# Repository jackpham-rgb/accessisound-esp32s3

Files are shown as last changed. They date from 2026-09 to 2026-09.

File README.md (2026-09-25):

# AccessiSound

An assistive device built around an ESP32-S3 that listens to the room,
recognizes sounds, and tells the user about them. It has three real
versions, described below. This repo holds the sound-recognition code, the
hardware documentation and a 3D model of the v2 enclosure.

| Version | What it was | Hardware |
|---|---|---|
| **v1** | Hackathon prototype, SoDA Hacks, March 7, 2026 | ESP32-S3-BOX-3 dev kit (borrowed) |
| **v2** | Rebuilt at home with my own parts and a custom enclosure | ESP32-S3 dev board, ESP32-CAM, 1.54 inch display |
| **v2.5** | Gift version built for a friend | v2 plus kitchen object recognition and a mochi animation |

## v1: the hackathon prototype

Built at SoDA Hacks, UC Berkeley, on Saturday, March 7, 2026. It ran on an
ESP32-S3-BOX-3, an off-the-shelf Espressif dev kit
([espressif/esp-box](https://github.com/espressif/esp-box)) that CSUA (the
Computer Science Undergraduate Association at my school) lent out for the
hackathon. I did not design or build an enclosure for v1. Its physical form
is the BOX-3 as sold, not something I made.

> It was my first hackathon, and I learned a lot from both the experience and the people I met there. I built an assistive device using an ESP32-S3 that could recognize speech and surrounding sounds, then provide real-time descriptions to support accessibility. I also trained the system using basic inputs, online datasets, and CSUA HPC resources.

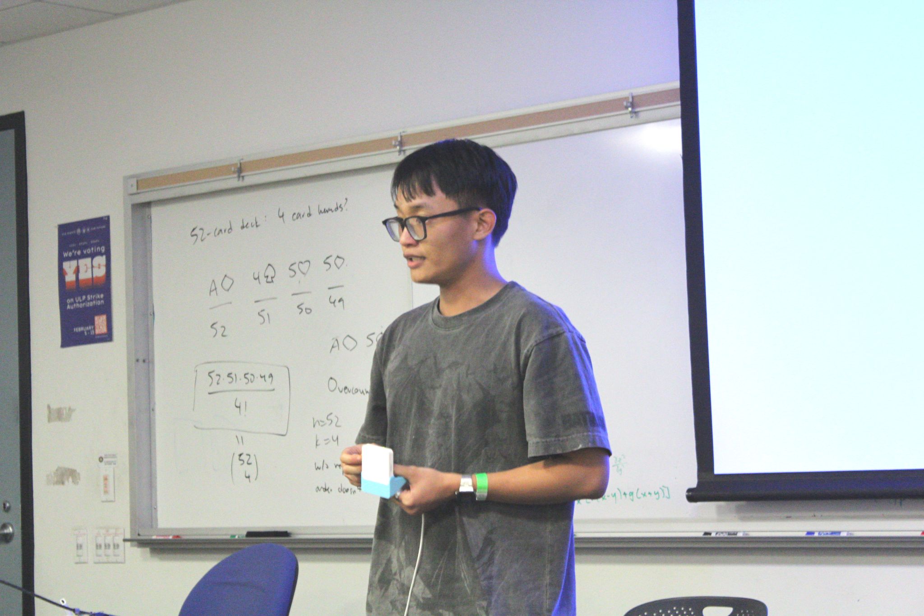
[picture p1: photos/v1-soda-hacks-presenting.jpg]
Presenting v1 at SoDA Hacks


*Presenting v1 at SoDA Hacks, holding the ESP32-S3-BOX-3.*

## v2: rebuilt at home

After the hackathon I bought my own ESP32 board and components and rebuilt
it as a custom device. Most parts came from AliExpress, but that seller is
gone. The display is a 1.54 inch full color TFT, 240 x 240 pixels, ST7789
driver, SPI interface, 3.3 V, 65K colors. An equivalent part is on Amazon:
[B0GVYMJVWH](https://www.amazon.com/dp/B0GVYMJVWH). Everything else was
generic online parts.

Components:

- ESP32-S3 dev board (the repo firmware targets the ESP32-S3-DevKitC-1)
- ESP32-CAM module
- 1.54 inch ST7789 SPI display (above)
- INMP441 I2S microphone
- USB-C charging circuit (TP4056 class module) and a small LiPo battery
- Vibration motor, buzzer and two status LEDs, as in the original parts list

I imitated the look of the ESP32-S3-BOX-3, but the finished enclosure ended
up looking like a vintage Macintosh 128K.

Even though there is no photo of the physical v2 unit, the picture below
accurately represents the model made using Autodesk Fusion.

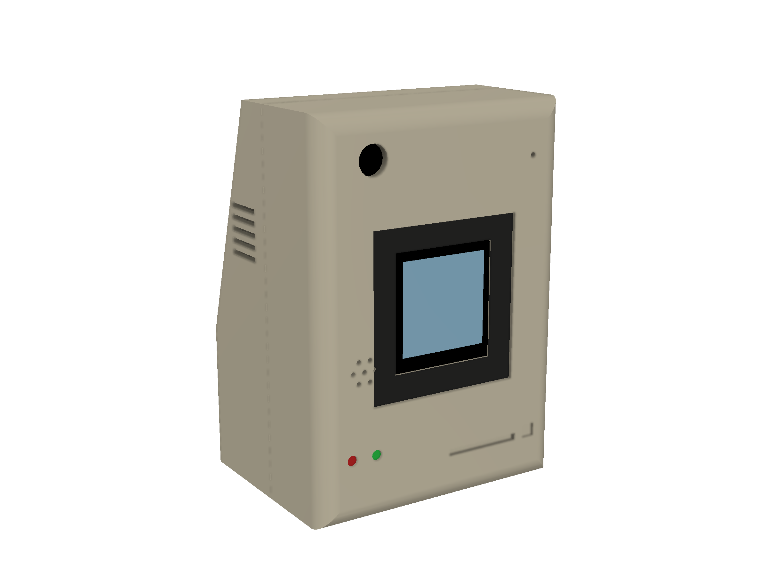
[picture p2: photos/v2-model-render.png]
v2 model, exterior


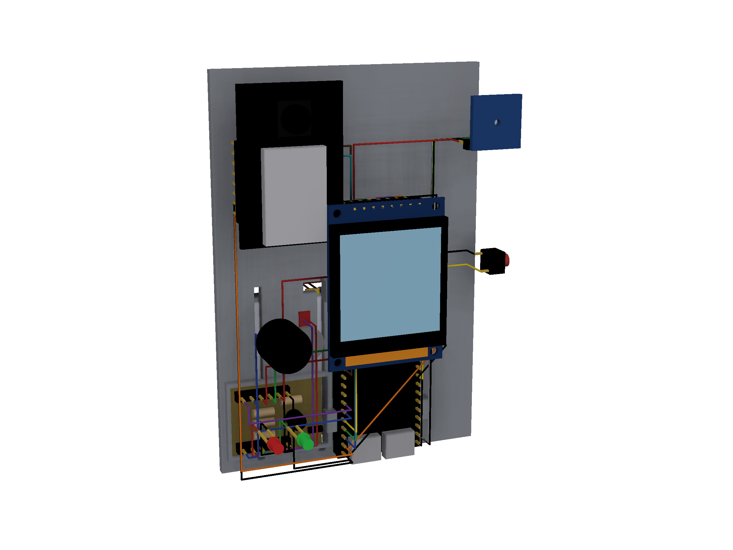
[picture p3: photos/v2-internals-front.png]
v2 model, internal layout and wiring


Model files, parts list with dimensions, wiring tables and print notes are
in [hardware/v2](hardware/v2/README.md):

- [Fusion 360 archive (.f3d)](hardware/v2/accessisound_v2_assembly.f3d) and [STEP](hardware/v2/accessisound_v2_assembly.step)
- STL files for the [front shell](hardware/v2/stl/enclosure_front.stl), [back shell](hardware/v2/stl/enclosure_back.stl), [mounting plate](hardware/v2/stl/mount_plate.stl), and one [build-plate layout](hardware/v2/stl/print_plate_layout.stl)

## v2.5: the gift version

I built this while moving out of the dorm for summer break. I adapted the
v1 to v2 design for a friend's needs: his family has hearing and visual
impairments. I added kitchen object recognition through the ESP32-CAM and a
cute mochi character animation on the display to make it feel friendlier.
I gave it to him as a thank you for helping me brainstorm the original
hackathon idea. He still uses it every day in his dorm kitchen.

This device used to be listed separately on my resume and site as "AI
Kitchen Accessibility Assistant". It is the same device, not a separate
project.

The camera and animation code is not in this repo yet. What is here is the
sound-recognition pipeline described next.

## How the sound recognition works

The device listens through a microphone, turns each 32 ms slice of audio
into 13 numbers (MFCCs), stacks 32 slices into a 0.53 second window, and
runs a small CNN over it. If the top guess is at least 72 percent
confident, it fires an alert. Everything runs entirely on the ESP32-S3.

`ml/visualize_pipeline.py` draws every step using the firmware's own math,
rewritten in NumPy. It doesn't need a large dataset or any dedicated
hardware, just numpy, scipy and matplotlib:

```bash
cd ml
pip install numpy scipy matplotlib
python visualize_pipeline.py            # built-in synthetic chime, or pass a WAV
python check_against_firmware.py        # optional: compiles the real firmware code with g++ and compares
```

The check compiles `firmware/src/feature_extractor.h` and compares it to the
NumPy version on real frames. They agree to about 3e-5, which is float32
rounding.

**1. One frame of audio to 13 numbers.** This figure follows a single 32 ms
frame (512 samples) through the seven steps of the feature extractor, one
panel per step, top to bottom:

1. The raw 16 kHz waveform, with the frame being processed marked in red.
2. Pre-emphasis, which boosts high frequencies where alarm and chime detail
   lives.
3. The Hamming window, which tapers the frame edges so the Fourier transform
   does not smear.
4. The power spectrum, the energy at each frequency (31.25 Hz per bin).
5. The mel filterbank, 26 triangular filters from 80 Hz to 8 kHz, narrow at
   low pitch and wide at high pitch like human hearing.
6. The log of the energy in each filter.
7. A DCT that compresses those 26 values into 13 MFCCs, the numbers the CNN
   actually receives.

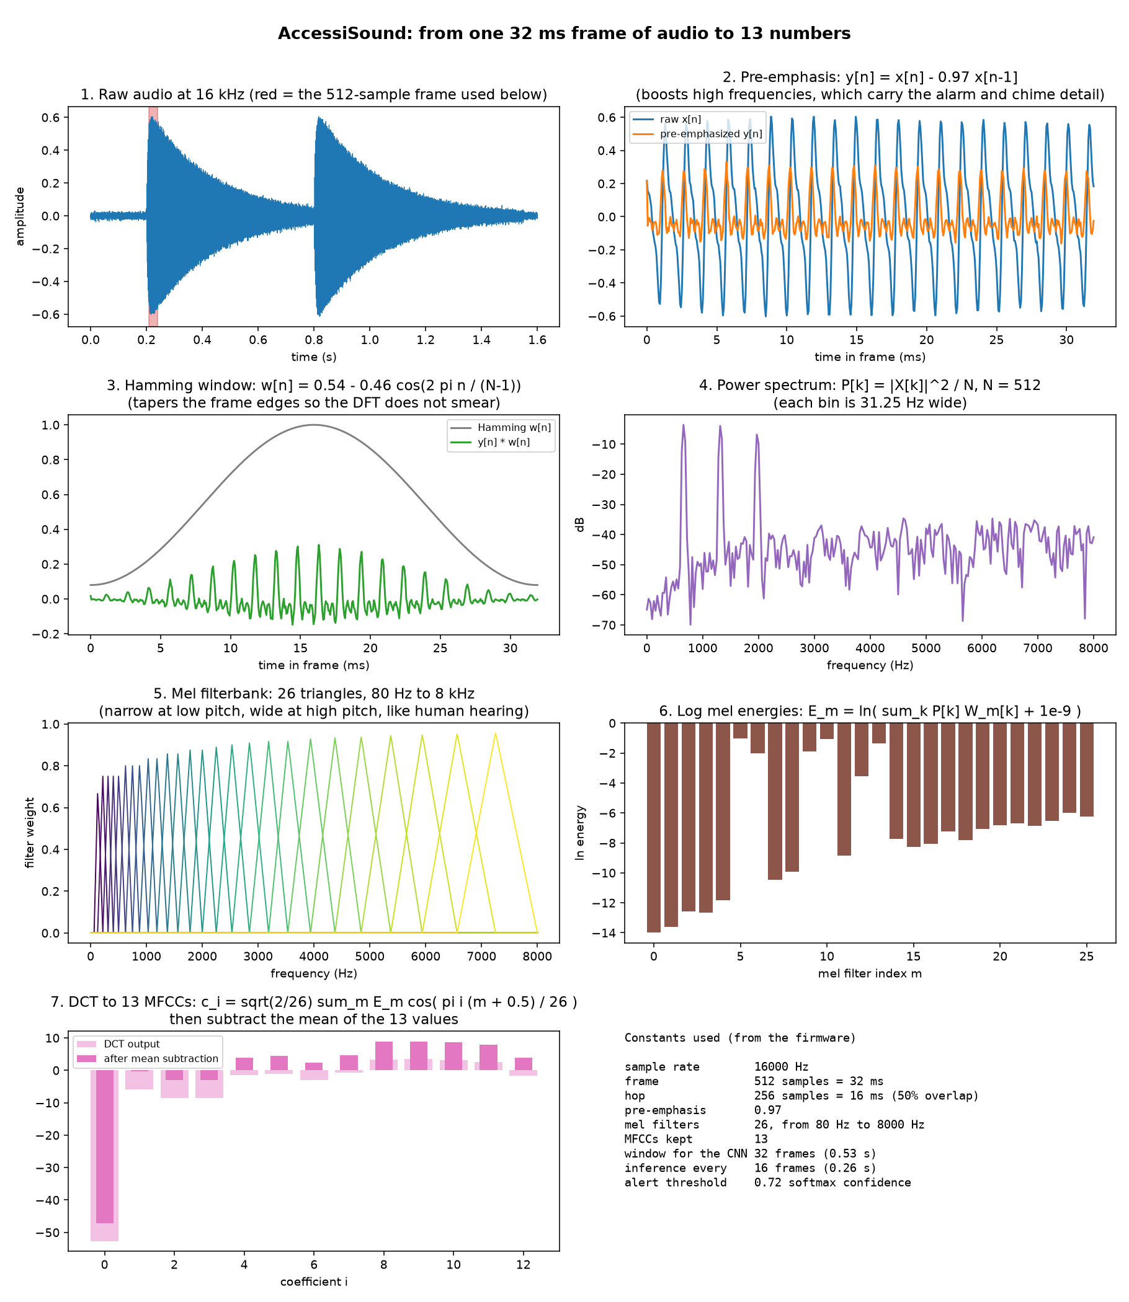
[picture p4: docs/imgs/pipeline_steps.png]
One frame, step by step


**2. The whole clip.** The same processing applied to every frame of a clip,
shown as four stacked views that share one time axis: the raw waveform, a
spectrogram (frequency content over time), the mel spectrogram (the same
information folded into 26 perceptual bands), and the MFCCs (13 rows per
frame). The cyan box marks the 32-frame window, about 0.53 seconds, that is
handed to the CNN.

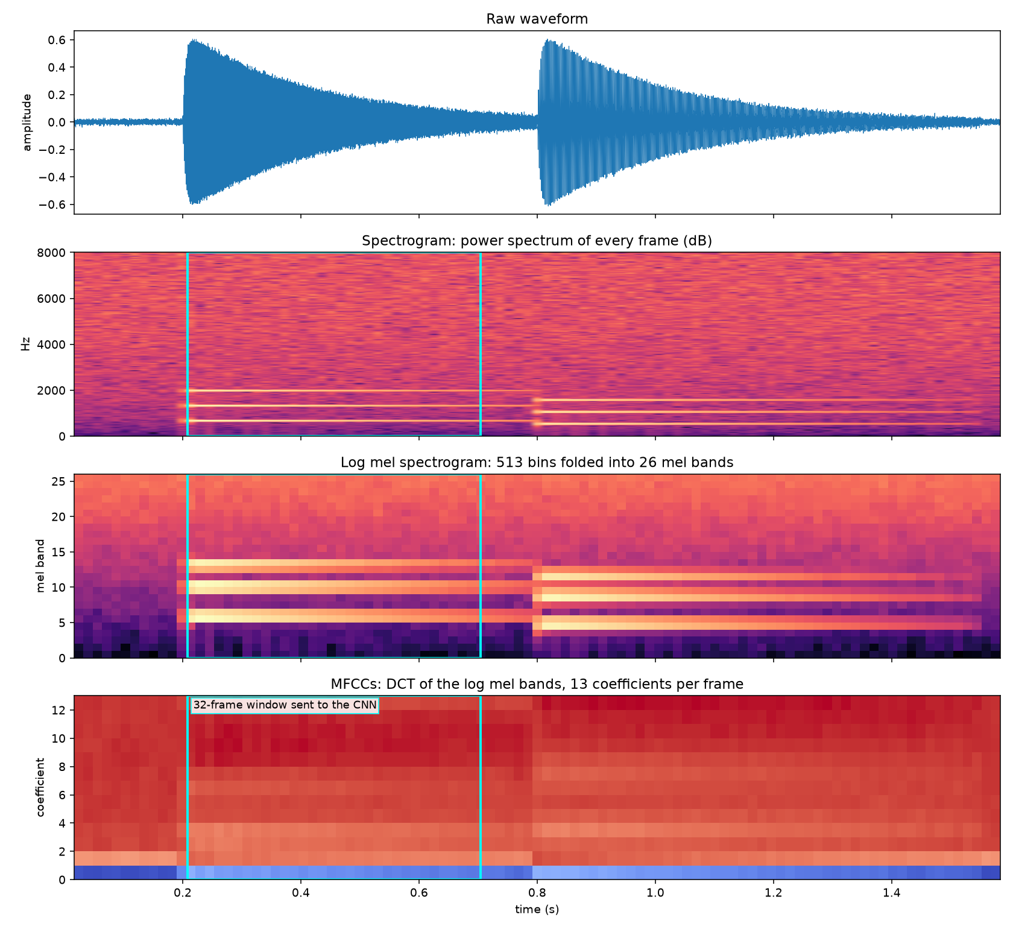
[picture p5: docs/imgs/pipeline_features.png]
Spectrogram to MFCC


**3. From MFCC window to alert.** The left panel shows the 32 x 13 MFCC window
going into the network. Next to it is the CNN itself (7,429 parameters: two
convolution blocks, global average pooling and two dense layers). The bottom
panels apply the alert rule from `firmware/src/main.cpp` to two example
outputs: in case A the top score is above 0.72, so the alert fires, and in
case B the top score is below 0.72, so the device stays quiet. The two sets
of scores are illustrations chosen to show the rule, not outputs of a
trained model.

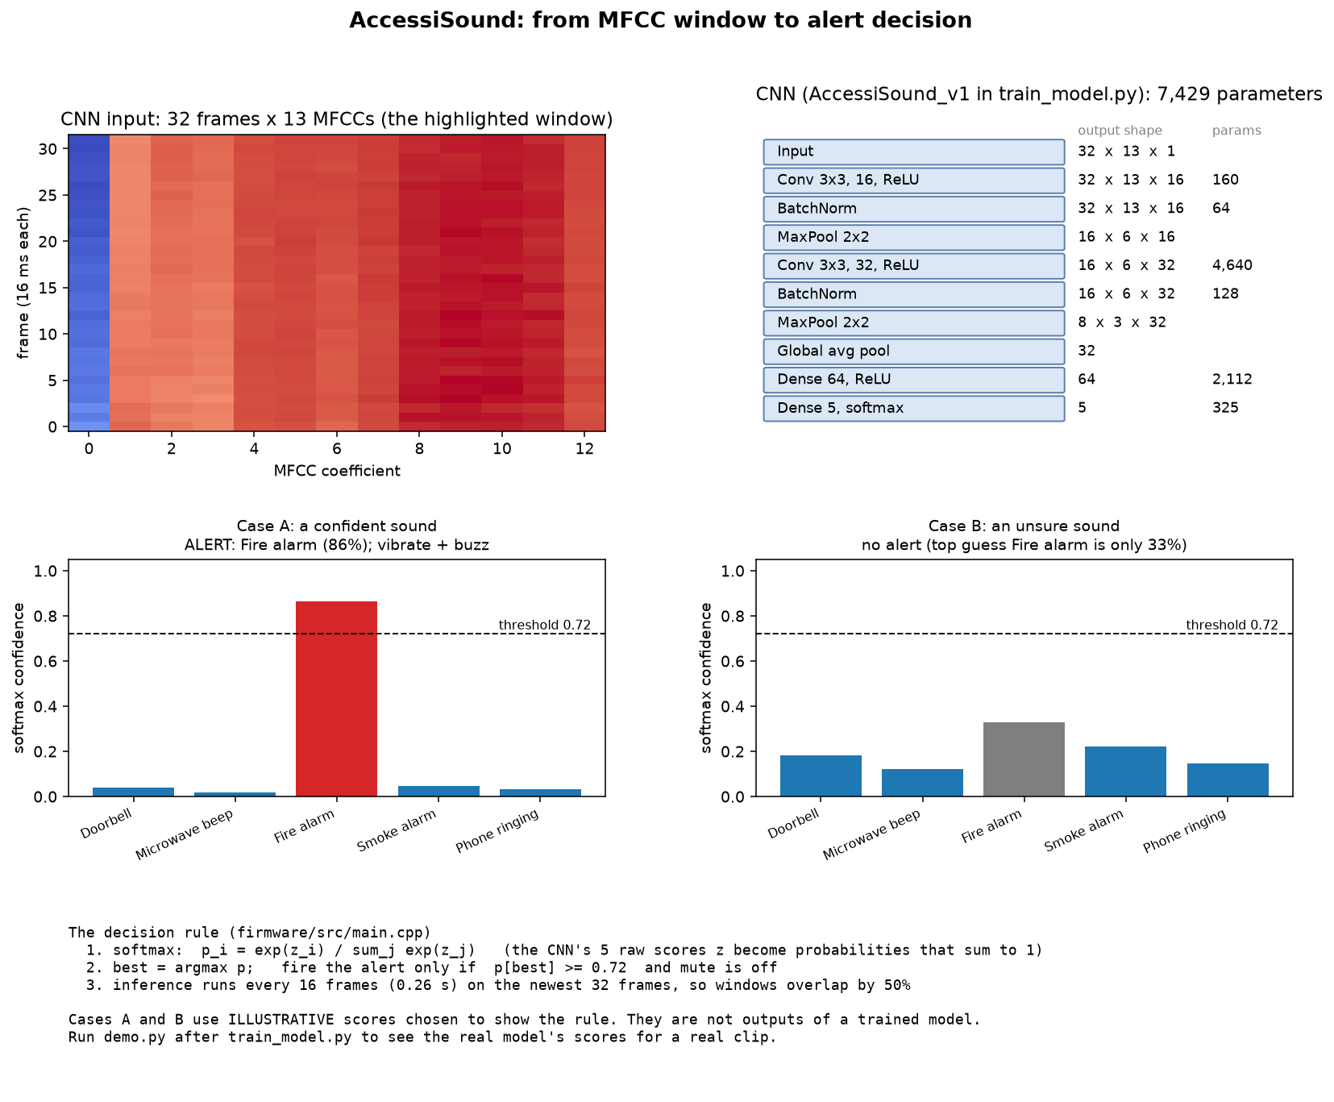
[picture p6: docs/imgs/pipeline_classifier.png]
Classifier and alert rule


**4. Firmware versus training features.** The same audio run through the
firmware's feature extractor (left) and through the librosa MFCC used by
`train_model.py` (middle), both scaled for display, plus the correlation
between the two for each coefficient (right). The patterns are similar but
not identical, which is the mismatch described in the known issues below.

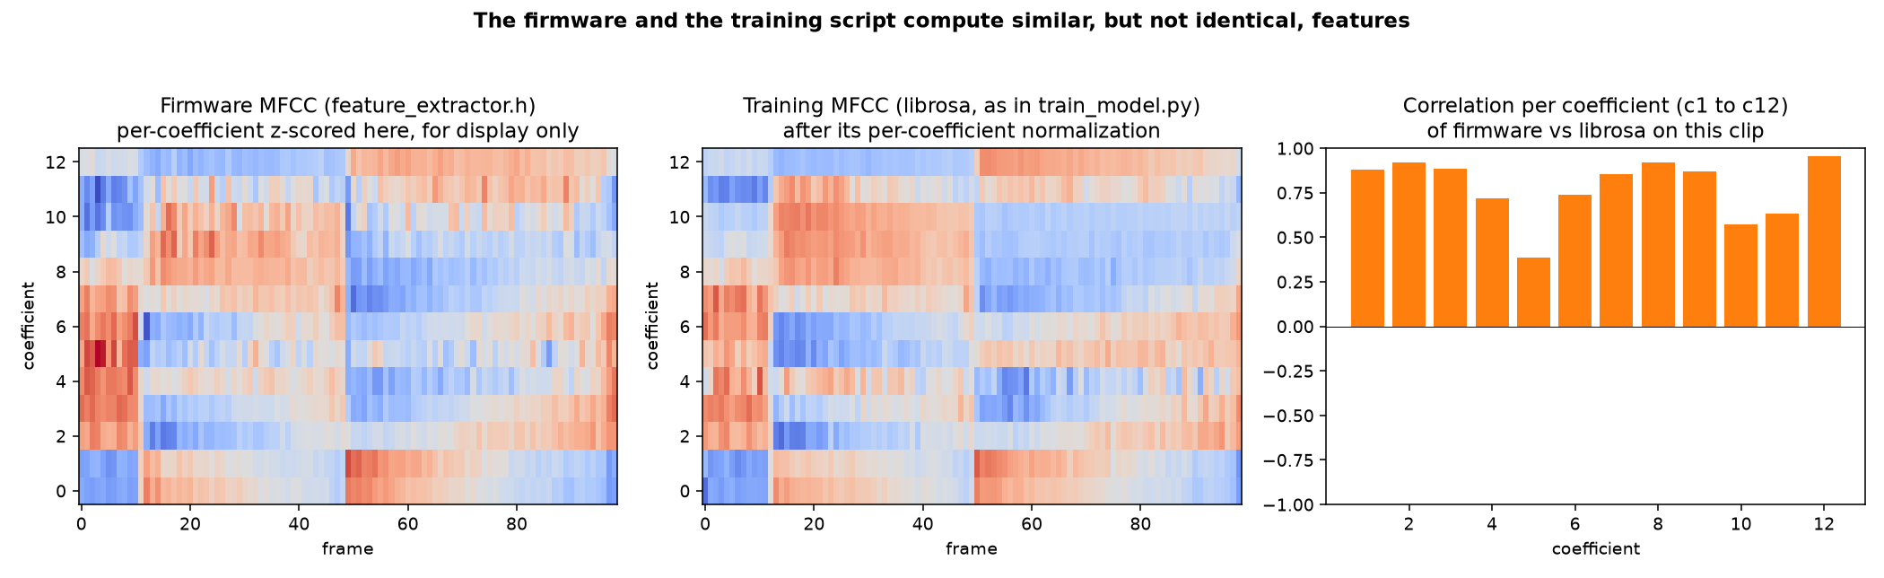
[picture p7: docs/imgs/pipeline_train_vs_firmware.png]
Firmware vs training MFCC


## Try the ML without hardware

```bash
git clone https://github.com/jackpham-rgb/accessisound-esp32s3.git
cd accessisound-esp32s3/ml
python -m venv .venv
source .venv/bin/activate      # or .venv\Scripts\activate on Windows
pip install -r requirements.txt
python train_model.py          # downloads ESC-50 (about 600 MB, one time), trains, exports
python demo.py                 # runs a random clip through the trained model
```

Quick check that the pipeline runs: `python train_model.py --skip-download --epochs 5`.

Training writes `models/sound_classifier.tflite`, `models/sound_model.h` (also
copied to `firmware/src/`) and `models/training_report.png`. Test accuracy on
this dataset is about 47 to 53 percent across 5 classes (chance is 20).
ESC-50 has no doorbell, smoke alarm or phone ring, so each class is trained
on the closest stand-in sound; see `TARGET_CLASSES` in `train_model.py`. To
train on real recordings, put 20 to 40 five-second WAV clips per sound in
`data/custom/<class_name>/`, add the folder to `TARGET_CLASSES`, and
re-run.

## Flash the firmware

The firmware in `firmware/` targets an ESP32-S3-DevKitC-1 with an INMP441
microphone, a vibration motor, a buzzer and two LEDs. Wiring for those is
in [hardware/v2](hardware/v2/README.md#wiring). Install
[PlatformIO](https://platformio.org/), then:

```bash
cd firmware
pio run --target upload --upload-port /dev/ttyUSB0   # or COM3 on Windows
pio device monitor
```

## Repository layout

```
firmware/        ESP32-S3 sound-recognition firmware (PlatformIO)
ml/              training, hardware-free demo, algorithm visualization
hardware/v2/     3D model, STL files, parts, wiring
docs/imgs/       algorithm figures
photos/          v1 presentation photo, v2 model renders
```

## Known issues and limits

- **Firmware and training use different features.** `train_model.py` uses
  librosa's MFCC, squeezes a whole 5 second clip into 32 frames, and
  normalizes each coefficient over time. The firmware adds pre-emphasis,
  starts its mel filters at 80 Hz, feeds 32 consecutive 16 ms frames (0.53
  s), and subtracts the mean across the 13 coefficients. On the same audio
  the two agree only partly (mean correlation 0.78, worst coefficient 0.39;
  figure 4). A model trained by this script and run by this firmware has
  never been checked end to end. This is the first thing to fix.
- **Accuracy is measured on stand-in sounds** (above), not on the real
  target sounds.
- **The sound classifier has no "background" class.** It always picks one
  of 5 sounds, so the 0.72 confidence threshold is the only thing stopping
  false alerts.
- **This repo does not contain the speech recognition, camera, display or
  mochi animation code** mentioned in the version notes.
- **The 3D model is a reconstruction.** Dimensions marked "assumed" in
  [hardware/v2](hardware/v2/README.md) need to be measured on real parts
  before printing.

## License

Code: MIT, see [LICENSE](LICENSE). The [ESC-50 dataset](https://github.com/karolpiczak/ESC-50)
used for training is CC-BY, separately from this repo's code.

## Credits

- [ESC-50](https://github.com/karolpiczak/ESC-50) dataset by Karol Piczak
- [TensorFlow Lite for Microcontrollers](https://www.tensorflow.org/lite/microcontrollers)
- [librosa](https://librosa.org/)
- [Espressif ESP-BOX](https://github.com/espressif/esp-box), the v1 hardware

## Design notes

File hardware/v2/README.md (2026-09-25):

# AccessiSound v2: enclosure, layout and wiring

This folder holds the CAD model of the v2 device: a custom enclosure in the
proportions of a vintage Macintosh 128K, with the boards laid out inside and
every wire drawn. The original v2 design files were lost with the laptop they
lived on, so the model was rebuilt in Autodesk Fusion from the repo docs, the
build description and published component dimensions. It has not been printed
or assembled.

v2 model

Inside the v2 model, front view
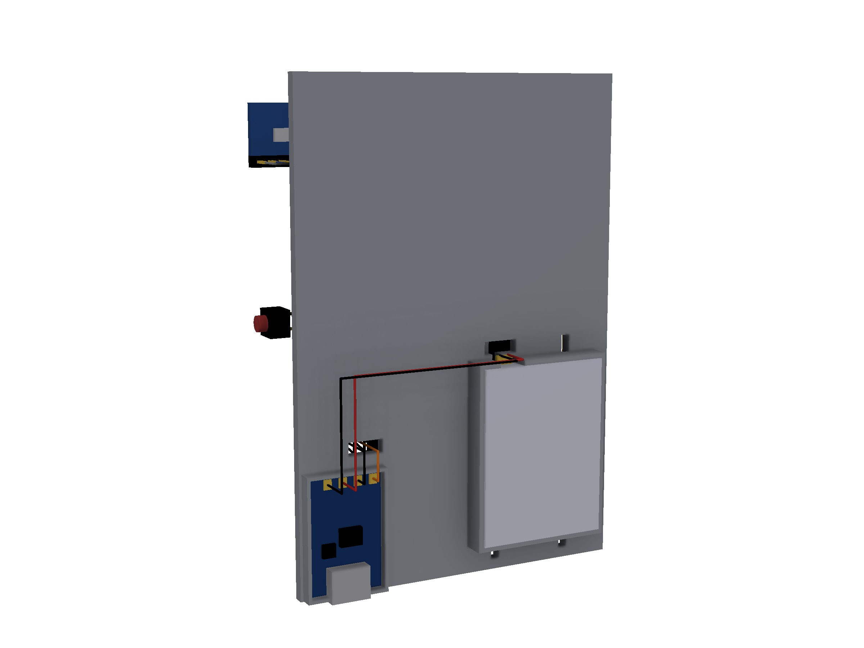
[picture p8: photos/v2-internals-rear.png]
Inside the v2 model, rear view


## Wiring diagram

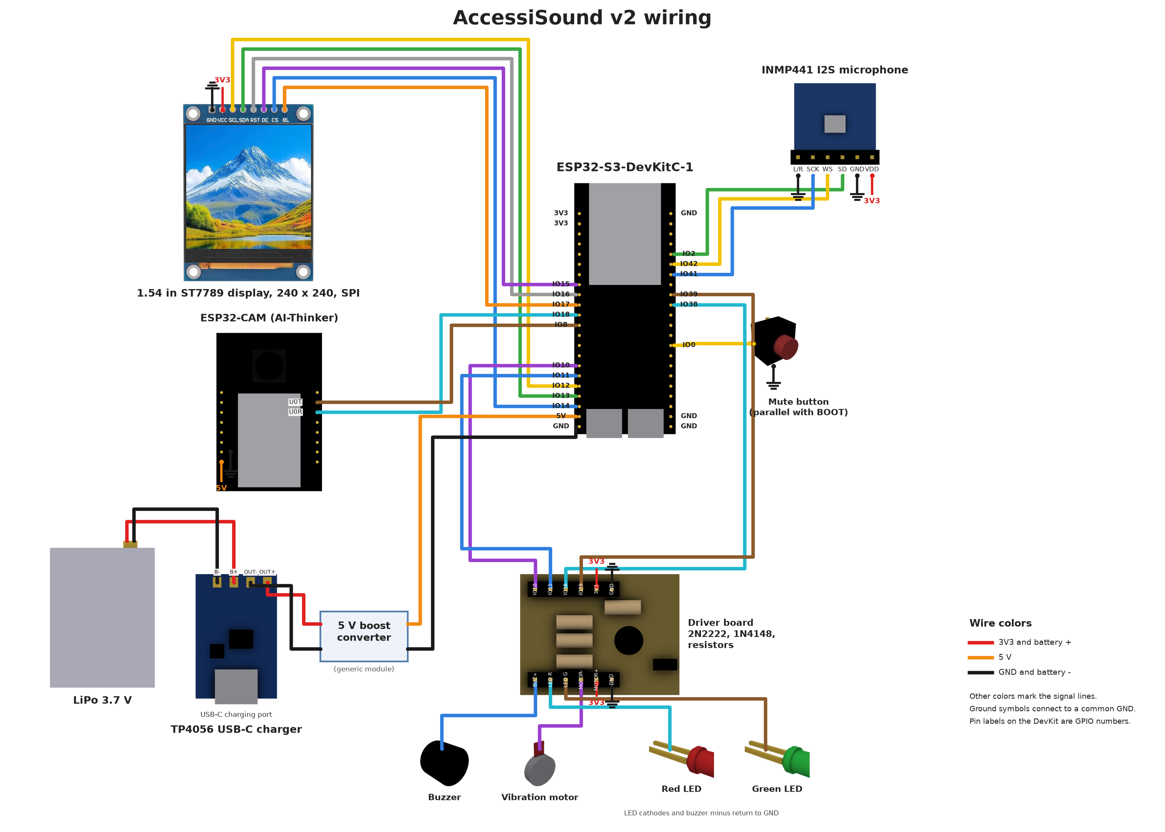
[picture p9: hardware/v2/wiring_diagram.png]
AccessiSound v2 wiring diagram


The diagram shows every connection in the build. Wire colors follow the key
at the bottom right: red for 3V3 and battery plus, orange for 5 V, black for
ground, and other colors for individual signal lines. Ground symbols join a
common GND. The labels on the ESP32-S3 header are GPIO numbers.

- **Display (top left).** The six SPI signals go from the display header to
  GPIO 12 (SCL), 13 (SDA), 16 (RST), 15 (DC), 14 (CS) and 17 (BL). The display
  also takes 3V3 and ground.
- **ESP32-CAM.** A two-wire serial link: the DevKit's GPIO 18 goes to the
  camera's U0R and GPIO 8 to U0T. The camera runs from 5 V.
- **Microphone (top right).** The INMP441 uses three I2S lines: SD to GPIO 2,
  WS to GPIO 42 and SCK to GPIO 41. VDD is 3V3, and GND and L/R are grounded
  so the mic reports on the left channel.
- **Mute button.** Wired to GPIO 0, in parallel with the DevKit's BOOT button.
- **Driver board (bottom centre).** GPIO 10, 11, 38 and 39 switch the
  vibration motor (through a 2N2222), the buzzer, and the red and green LEDs.
- **Power (bottom left).** The LiPo connects to the TP4056 USB-C charger, whose
  output goes through a 5 V boost converter to the DevKit's 5V and GND pins.

The display is a photo of the actual module. The other parts are renders from
the Fusion model, drawn at their real proportions so the pins line up with the
header positions. The generator script and part images are in
[diagram/](diagram/); replacing a render with a product photo only needs a new
image and its pin positions in `parts.json`.

## Files

| File | What it is |
|---|---|
| `accessisound_v2_assembly.f3d` | Fusion 360 archive: the full assembly, one component per part, editable |
| `accessisound_v2_assembly.step` | Same assembly as STEP, for any other CAD program |
| `stl/enclosure_front.stl` | Front shell, posed face down for printing |
| `stl/enclosure_back.stl` | Back shell, posed open side down for printing |
| `stl/mount_plate.stl` | Internal mounting plate |
| `stl/print_plate_layout.stl` | All three parts arranged on one build plate (251 x 116 mm, fits a 256 mm bed) |
| `wiring_diagram.png` | The wiring diagram above |
| `diagram/` | Script and part images that generate the diagram |

All STL files are in millimetres and were checked to be closed solids (no
open or shared edges). Supports are needed for the back shell and the plate.
The files have not been test printed. The shells meet at a butt joint with a
2 mm alignment lip on the back shell; glue them, or add screw bosses.

## Size and layout

Outside: 82 wide x 116 tall x 64 deep mm. Front face on the left of the
diagram, parts stacked front to back:

```
front wall 2.4 | display + camera + mic | wire zone | DevKit | plate | battery + charger
```

- Front wall: recessed dark bezel, display window, camera window (top left),
  mic port (top right), buzzer grille, two status LED holes, a decorative
  floppy-style slot, and a mute button hole in the right wall.
- Bottom wall: USB-C openings for the DevKit (flashing) and the charger.
- Back shell: side vents and a sloped rear like the Mac 128K.
- Mounting plate: side blocks that locate the DevKit, pockets for the
  charger, battery and driver board, two strap slots and two wire slots.

## Parts and dimensions

The "Source" column says where each size comes from. Values marked typical
are common figures for that class of part and should be measured on the
actual part before printing.

| Part | Size used (mm) | Source |
|---|---|---|
| ESP32-S3-DevKitC-1 v1.1 | 25.4 x 62.86 board | Espressif's official DXF (`dl.espressif.com/dl/schematics/esp_idf/DXF_ESP32-S3-DevKitC-1_V1.1_20220429.dxf`). Third-party pages round this to 70 x 28. Header pitch 2.54; row spacing about 22.7 to 22.9 (0.9 in nominal), 22 pins each. Board thickness 1.6 and module height 3.1 are typical. |
| ESP32-CAM (AI-Thinker) | 40.5 x 27 x 4.5 board | Two independent listings. Lens position and lens height above the board (5) are typical. |
| 1.54 inch TFT, 240x240, ST7789 | PCB 43.5 x 32, glass 31.7 x 34.3 | Measured from product photos of the module (Amazon listing B0GVYMJVWH). Thickness (glass 2.6 + PCB 1.0) is typical. The active area is 27.72 mm square, from the 1.54 inch diagonal. |
| INMP441 microphone board | 14 x 14 | Typical |
| TP4056 charger, USB-C | 26 x 17 | Typical module size |
| LiPo cell | 40 x 30 x 6 (a 603040 class cell) | Typical, actual cell varies |
| Passive buzzer | 12 dia x 9.5 | Typical |
| Coin vibration motor | 10 dia x 2.7 | Typical |
| 3 mm LEDs, 6 mm tact switch | standard | Standard |

## Wiring tables

The diagram above is drawn from these tables. Wires in the 3D model are
illustrative routes, each on its own depth plane, not a routed harness.

### A. Pins used by `firmware/src/main.cpp`

| From | To |
|---|---|
| Mic WS | GPIO 42 |
| Mic SCK | GPIO 41 |
| Mic SD | GPIO 2 |
| Mic VDD | 3V3 |
| Mic GND, mic L/R | GND (L/R low = left channel, which the firmware reads) |
| GPIO 10 | 1 kΩ to the base of an NPN transistor (2N2222) |
| Transistor emitter | GND |
| Transistor collector | motor minus; motor plus to 3V3 |
| Diode (1N4148) | across the motor, cathode to 3V3 (flyback) |
| GPIO 11 | 100 Ω to the buzzer plus; buzzer minus to GND |
| GPIO 38 | 220 Ω to the red LED anode; cathode to GND |
| GPIO 39 | 220 Ω to the green LED anode; cathode to GND |
| GPIO 0 | mute (the DevKit BOOT button; the model adds an external button in parallel) |

### B. Reference pin assignment for the display, camera and charger

The firmware in this repo covers sound recognition only, so the display,
camera and charger pins are defined here. They avoid the strapping pins (0,
3, 45, 46), the USB pins (19, 20) and the pins in table A.

| Part | Wire | ESP32-S3 |
|---|---|---|
| Display | GND, VCC | GND, 3V3 |
| Display | SCL, SDA | GPIO 12, GPIO 13 |
| Display | CS, DC, RST | GPIO 14, GPIO 15, GPIO 16 |
| Display | BL | GPIO 17 |
| ESP32-CAM | 5V, GND | 5V pin, GND |
| ESP32-CAM | U0R (GPIO 3) from ESP32-S3 TX | GPIO 18 |
| ESP32-CAM | U0T (GPIO 1) to ESP32-S3 RX | GPIO 8 |
| Charger | OUT+ / OUT- | 5 V boost input / GND |
| Charger | B+ / B- | LiPo red / black |

**Power note.** A TP4056 outputs the battery voltage (3.0 to 4.2 V), not 5 V,
while the DevKit's 5V pin needs about 5 V. A 5 V boost converter (or a
charger-plus-boost module) therefore sits between the charger output and the
DevKit, as drawn in the diagram. The 3D model does not include the converter.

**Header order.** The ESP32-CAM header order used in the model (5V, GND,
IO12, IO13, IO15, IO14, IO2, IO4 on one side; 3V3, IO16, IO0, GND, VCC, U0R,
U0T, GND on the other) is the commonly published AI-Thinker order. The INMP441
pin order differs between breakout boards, so follow the silkscreen on the
board in use.

## Notes on the wiring

- A 1 kΩ base resistor drives the motor transistor. A 100 Ω resistor there
  would pull about 26 mA from a 3.3 V GPIO, more than an ESP32-S3 pin should
  source.
- A motor driven through a transistor needs a flyback diode across the
  motor, so the design includes a 1N4148.

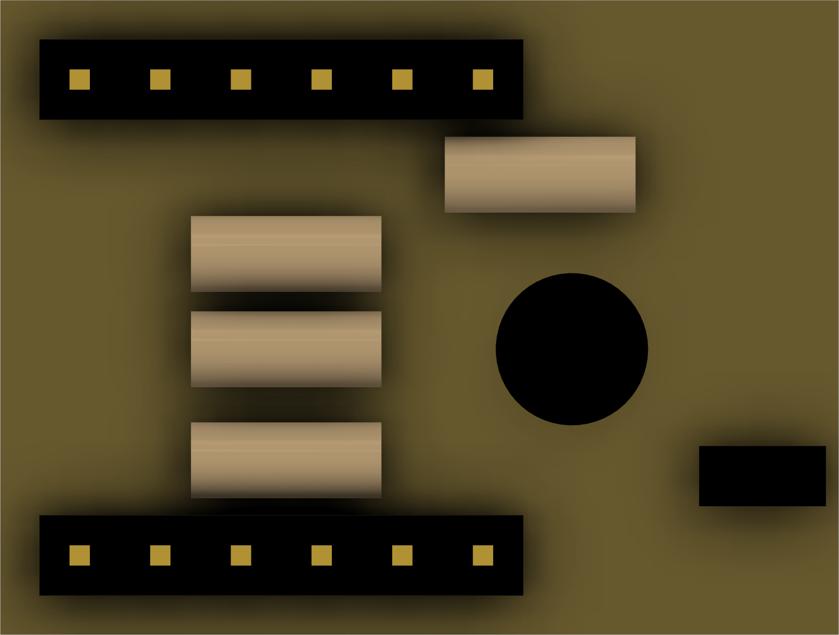
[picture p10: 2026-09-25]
hardware/v2/diagram/driver_crop.png

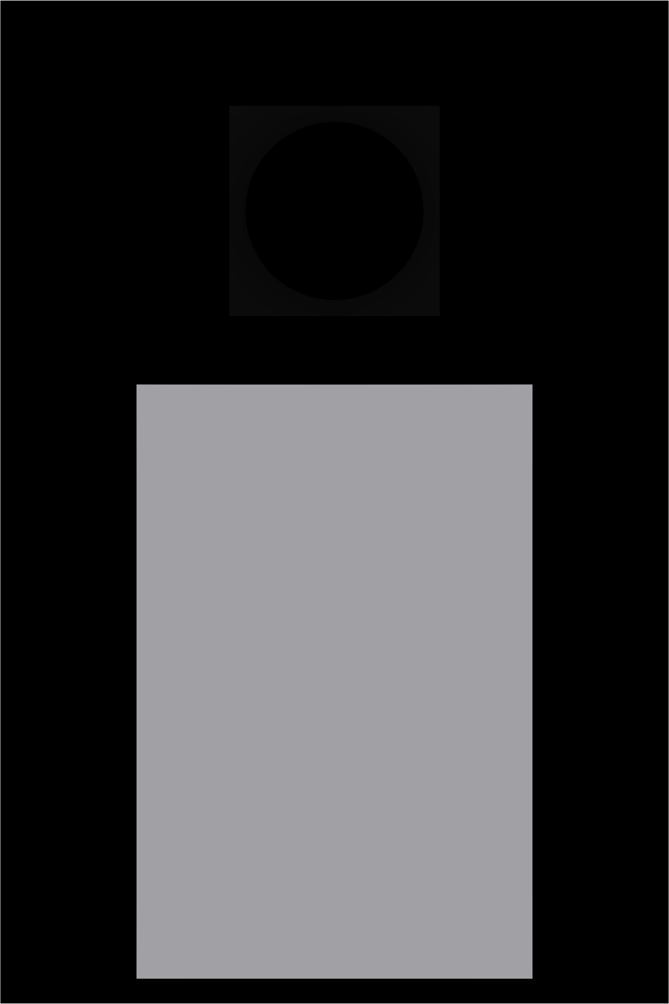
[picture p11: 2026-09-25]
hardware/v2/diagram/cam_crop.png

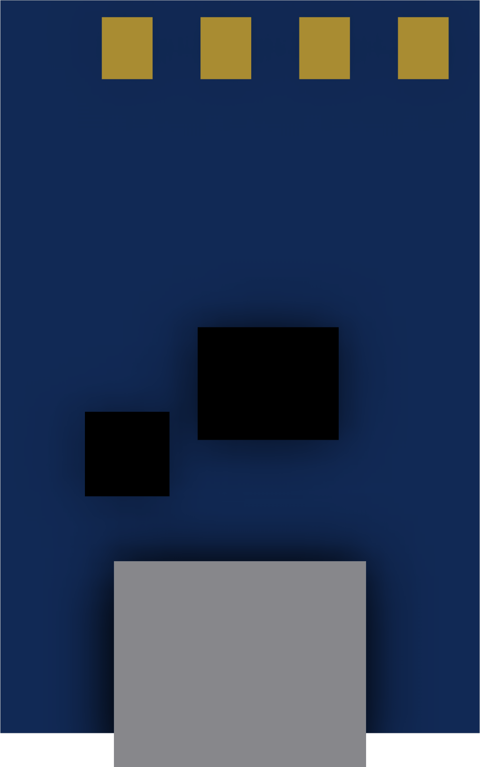
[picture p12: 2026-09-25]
hardware/v2/diagram/charger_crop.png

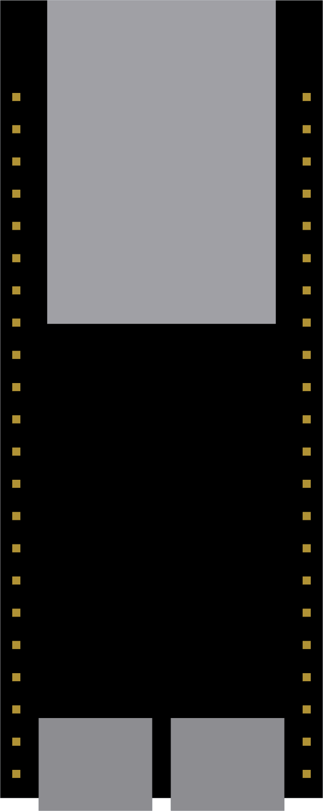
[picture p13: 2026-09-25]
hardware/v2/diagram/devkit_crop.png

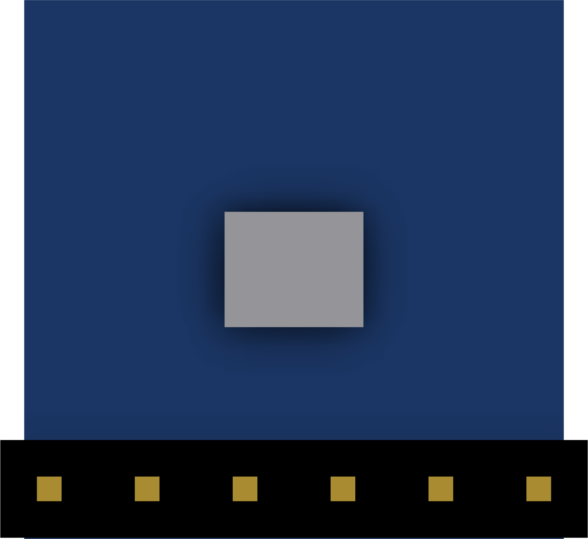
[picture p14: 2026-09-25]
hardware/v2/diagram/mic_crop.png

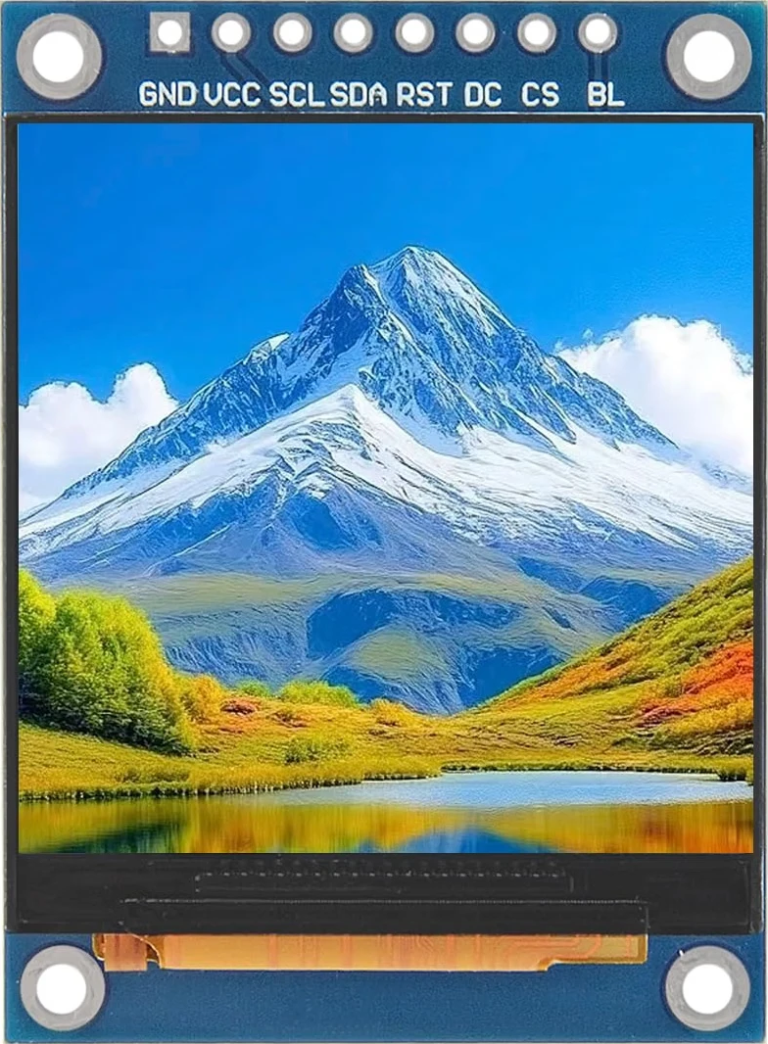
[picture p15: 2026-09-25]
hardware/v2/diagram/display_photo_crop.png

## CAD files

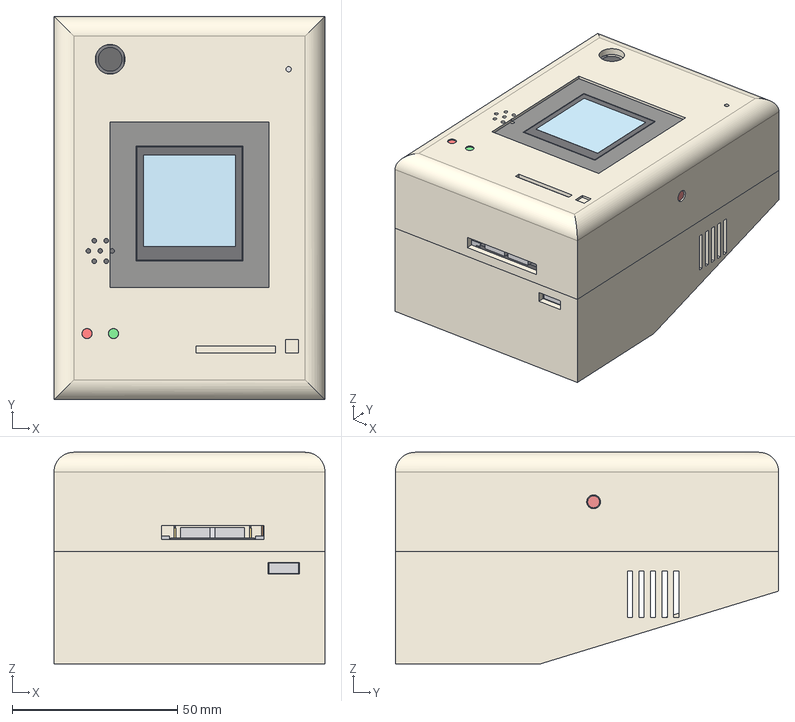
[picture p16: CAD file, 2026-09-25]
hardware/v2/accessisound_v2_assembly.step
82.0 x 116.0 x 64.0 mm

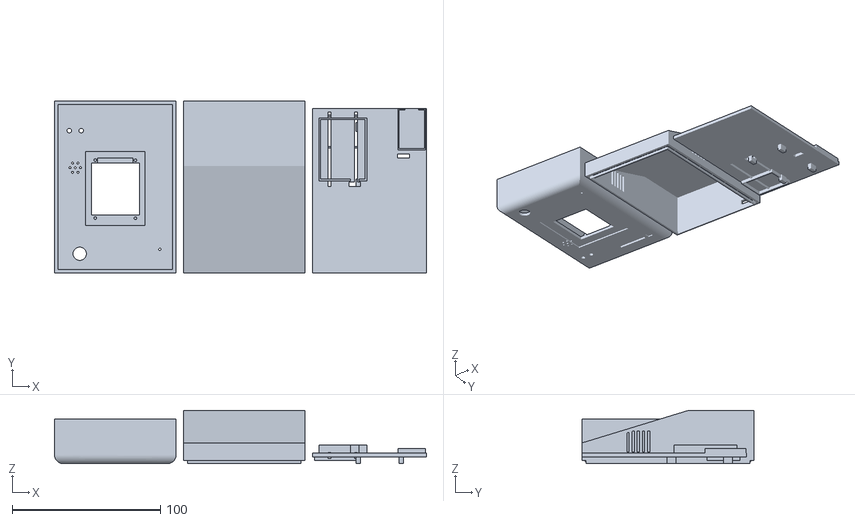
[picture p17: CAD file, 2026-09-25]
hardware/v2/stl/print_plate_layout.stl
250.8 x 116.0 x 36.0

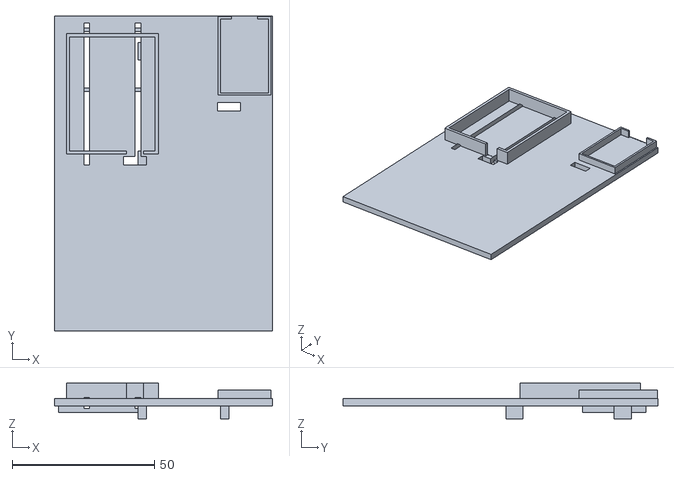
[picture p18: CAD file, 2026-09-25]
hardware/v2/stl/mount_plate.stl
76.8 x 110.8 x 12.6

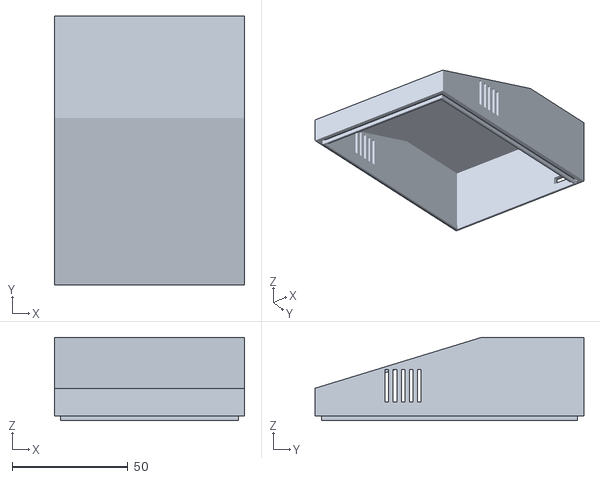
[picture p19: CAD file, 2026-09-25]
hardware/v2/stl/enclosure_back.stl
82.0 x 116.0 x 36.0

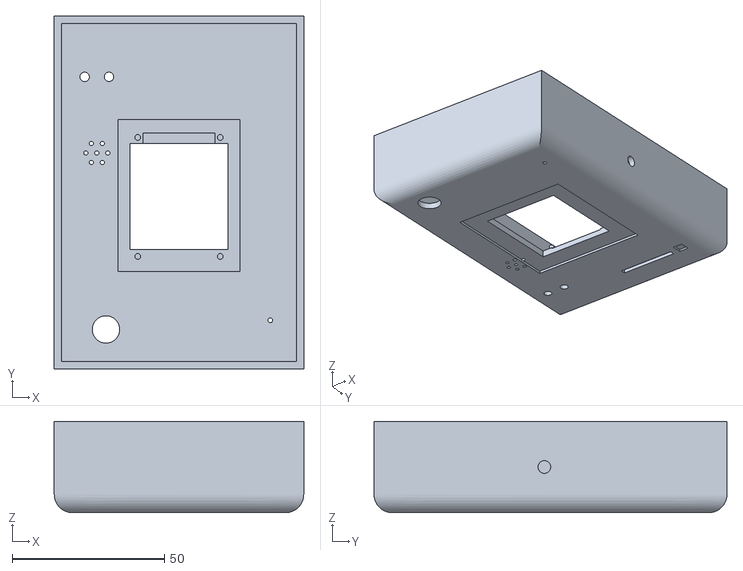
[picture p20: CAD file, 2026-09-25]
hardware/v2/stl/enclosure_front.stl
82.0 x 116.0 x 30.0

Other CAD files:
hardware/v2/accessisound_v2_assembly.f3d

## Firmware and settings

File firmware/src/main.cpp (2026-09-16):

/*
 * AccessiSound: ESP32-S3 Accessibility Sound Recognition Assistant
 * Hackathon Prototype v1.0
 *
 * Target Board : ESP32-S3-DevKitC-1 (or any ESP32-S3 with MEMS mic)
 * Framework    : Arduino (ESP-IDF compatible)
 *
 * Audio pipeline:
 *   I2S mic  →  ring buffer  →  FFT feature extraction
 *   →  threshold classifier  →  vibration / speaker alert
 *
 * Recognised sound classes (index -> label):
 *   0  doorbell      3  smoke_alarm
 *   1  microwave     4  phone_ring
 *   2  fire_alarm
 *
 * NOTE: the model is a plain 5-way softmax (see ml/train_model.py) with no
 * trained "background/silence" class, so it always picks one of the 5 real
 * classes as "most likely," even on silence or unrelated noise. The
 * CONFIDENCE_THR check below is the only thing stopping that from firing
 * false alerts constantly; it is not a substitute for an actual negative
 * class, which would need background-noise clips added to training.
 */

#include <Arduino.h>
#include <driver/i2s.h>
#include "sound_model.h"        // generated TFLite flatbuffer header
#include "feature_extractor.h"  // MFCC / FFT helpers
#include "alert_manager.h"      // vibration + speaker output

// ── Pin definitions ──────────────────────────────────────────────────────────
#define I2S_WS_PIN      42
#define I2S_SCK_PIN     41
#define I2S_SD_PIN      2

#define VIBRATION_PIN   10
#define SPEAKER_PIN     11
#define LED_RED_PIN     38
#define LED_GREEN_PIN   39
#define BOOT_BTN_PIN    0       // onboard BOOT button (mute toggle)

// ── Audio constants ───────────────────────────────────────────────────────────
#define SAMPLE_RATE     16000   // Hz, matches training pipeline
#define FRAME_SIZE      512     // samples per FFT frame
#define HOP_SIZE        256     // 50 % overlap
#define N_MFCC          13      // MFCC coefficients per frame
#define WINDOW_FRAMES   32      // frames stacked into one inference window
#define CONFIDENCE_THR  0.72f   // minimum confidence to fire an alert

// ── Sound label table ─────────────────────────────────────────────────────────
// Must match LABEL_NAMES in ml/train_model.py exactly (same order, same
// count) -- this is the model's real output layer, not a documentation
// list. A mismatch here silently misreads the output tensor.
static const char* SOUND_LABELS[] = {
    "Doorbell",
    "Microwave beep",
    "Fire alarm",
    "Smoke alarm",
    "Phone ringing"
};
static const uint8_t N_CLASSES = sizeof(SOUND_LABELS) / sizeof(SOUND_LABELS[0]);

// ── Globals ───────────────────────────────────────────────────────────────────
static int16_t  audioBuffer[FRAME_SIZE * 2];   // double-buffer
static float    mfccWindow[WINDOW_FRAMES][N_MFCC];
static uint8_t  frameIdx = 0;
static bool     muteMode = false;

AlertManager    alertMgr(VIBRATION_PIN, SPEAKER_PIN);
FeatureExtractor feat(SAMPLE_RATE, FRAME_SIZE, HOP_SIZE, N_MFCC);

// TFLite micro runtime (initialised in setup)
#include <TensorFlowLite_ESP32.h>
#include "tensorflow/lite/micro/all_ops_resolver.h"
#include "tensorflow/lite/micro/micro_interpreter.h"
#include "tensorflow/lite/schema/schema_generated.h"

static const int kTensorArenaSize = 60 * 1024;
static uint8_t   tensorArena[kTensorArenaSize];
static tflite::MicroInterpreter* interpreter = nullptr;
static TfLiteTensor* inputTensor  = nullptr;
static TfLiteTensor* outputTensor = nullptr;

// ── I2S initialisation ────────────────────────────────────────────────────────
void initI2S() {
    i2s_config_t cfg = {
        .mode                 = (i2s_mode_t)(I2S_MODE_MASTER | I2S_MODE_RX),
        .sample_rate          = SAMPLE_RATE,
        .bits_per_sample      = I2S_BITS_PER_SAMPLE_16BIT,
        .channel_format       = I2S_CHANNEL_FMT_ONLY_LEFT,
        .communication_format = I2S_COMM_FORMAT_STAND_I2S,
        .intr_alloc_flags     = ESP_INTR_FLAG_LEVEL1,
        .dma_buf_count        = 4,
        .dma_buf_len          = FRAME_SIZE,
        .use_apll             = false,
        .tx_desc_auto_clear   = false,
        .fixed_mclk           = 0
    };
    i2s_pin_config_t pins = {
        .bck_io_num   = I2S_SCK_PIN,
        .ws_io_num    = I2S_WS_PIN,
        .data_out_num = I2S_PIN_NO_CHANGE,
        .data_in_num  = I2S_SD_PIN
    };
    ESP_ERROR_CHECK(i2s_driver_install(I2S_NUM_0, &cfg, 0, nullptr));
    ESP_ERROR_CHECK(i2s_set_pin(I2S_NUM_0, &pins));
    Serial.println("[I2S] Driver installed at 16 kHz, 16-bit mono.");
}

// ── TFLite micro initialisation ───────────────────────────────────────────────
void initModel() {
    static tflite::AllOpsResolver resolver;
    const tflite::Model* model = tflite::GetModel(sound_model_data);

    if (model->version() != TFLITE_SCHEMA_VERSION) {
        Serial.println("[TFLite] ERROR: Model schema version mismatch!");
        while (true) delay(1000);
    }

    static tflite::MicroInterpreter staticInterp(
        model, resolver, tensorArena, kTensorArenaSize);
    interpreter = &staticInterp;

    if (interpreter->AllocateTensors() != kTfLiteOk) {
        Serial.println("[TFLite] ERROR: AllocateTensors() failed!");
        while (true) delay(1000);
    }

    inputTensor  = interpreter->input(0);
    outputTensor = interpreter->output(0);
    Serial.printf("[TFLite] Model loaded. Input shape: [1, %d, %d, 1]\n",
                  WINDOW_FRAMES, N_MFCC);
}

// ── Read one audio frame from I2S ─────────────────────────────────────────────
bool readAudioFrame() {
    size_t bytesRead = 0;
    esp_err_t err = i2s_read(I2S_NUM_0,
                             audioBuffer,
                             FRAME_SIZE * sizeof(int16_t),
                             &bytesRead,
                             pdMS_TO_TICKS(100));
    return (err == ESP_OK && bytesRead > 0);
}

// ── Run inference and return best class index ─────────────────────────────────
int8_t runInference(float confidence[]) {
    // Copy MFCC window into model input tensor
    for (int f = 0; f < WINDOW_FRAMES; ++f)
        for (int c = 0; c < N_MFCC; ++c)
            inputTensor->data.f[f * N_MFCC + c] = mfccWindow[f][c];

    if (interpreter->Invoke() != kTfLiteOk) {
        Serial.println("[TFLite] Invoke() failed.");
        return -1;
    }

    // Softmax output: find argmax
    int8_t bestClass = 0;
    float  bestScore = 0.0f;
    for (uint8_t i = 0; i < N_CLASSES; ++i) {
        float score = outputTensor->data.f[i];
        confidence[i] = score;
        if (score > bestScore) {
            bestScore = score;
            bestClass = i;
        }
    }
    return bestClass;
}

// ── setup() ───────────────────────────────────────────────────────────────────
void setup() {
    Serial.begin(115200);
    delay(500);
    Serial.println("\n=== AccessiSound v1.0 - ESP32-S3 ===");

    // GPIO setup
    pinMode(LED_RED_PIN,   OUTPUT);
    pinMode(LED_GREEN_PIN, OUTPUT);
    pinMode(BOOT_BTN_PIN,  INPUT_PULLUP);
    digitalWrite(LED_GREEN_PIN, HIGH);  // ready indicator

    alertMgr.begin();
    feat.begin();
    initI2S();
    initModel();

    Serial.println("[SYSTEM] Listening for sounds...");
}

// ── loop() ────────────────────────────────────────────────────────────────────
void loop() {
    // Mute toggle via BOOT button
    if (digitalRead(BOOT_BTN_PIN) == LOW) {
        muteMode = !muteMode;
        Serial.printf("[BUTTON] Mute %s\n", muteMode ? "ON" : "OFF");
        delay(300);  // debounce
    }

    if (!readAudioFrame()) return;

    // Compute MFCCs for this frame and slide into window
    float frameMFCC[N_MFCC];
    feat.computeMFCC(audioBuffer, FRAME_SIZE, frameMFCC);

    // Shift window left, append new frame
    memmove(mfccWindow, mfccWindow + N_MFCC,
            (WINDOW_FRAMES - 1) * N_MFCC * sizeof(float));
    memcpy(mfccWindow[WINDOW_FRAMES - 1], frameMFCC,
           N_MFCC * sizeof(float));

    frameIdx++;
    // Run inference every HOP_SIZE frames (50 % overlap)
    if (frameIdx < (WINDOW_FRAMES / 2)) return;
    frameIdx = 0;

    float confidence[N_CLASSES];
    int8_t predicted = runInference(confidence);

    if (predicted < 0) return;
    if (confidence[predicted] < CONFIDENCE_THR) return;
    if (muteMode) return;

    // ── Alert! ──────────────────────────────────────────────────────────────
    Serial.printf("[DETECTED] %s (%.1f%%)\n",
                  SOUND_LABELS[predicted],
                  confidence[predicted] * 100.0f);

    digitalWrite(LED_RED_PIN, HIGH);
    alertMgr.triggerAlert(predicted, confidence[predicted]);
    digitalWrite(LED_RED_PIN, LOW);
}

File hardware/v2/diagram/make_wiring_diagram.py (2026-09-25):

#!/usr/bin/env python3
"""Draw the AccessiSound v2 wiring diagram from part images.

Part images live in the same folder as this script (see parts.json). Each
face-on part image is cropped to the part's silhouette, so a pin's position in
millimetres maps linearly onto the image. To use a real product photo instead
of a rendered part, add the photo, then give it a `parts.json` entry (size in
mm) and update the pin positions used below.

    python make_wiring_diagram.py
"""
from __future__ import annotations

import json
import pathlib

import matplotlib
matplotlib.use("Agg")
import matplotlib.pyplot as plt
import numpy as np
from PIL import Image

HERE = pathlib.Path(__file__).resolve().parent
PARTS = HERE
META = json.loads((PARTS / "parts.json").read_text())

W, H = 2800, 2000
COL = dict(red="#e02020", orange="#f28a12", black="#1a1a1a", yellow="#f2c200", green="#3aa843",
           blue="#2f7fe0", purple="#9a3fd0", white="#9a9a9a", cyan="#22b8cf", brown="#8a5a2b")

fig = plt.figure(figsize=(W / 100, H / 100), dpi=100)
ax = fig.add_axes([0, 0, 1, 1])
ax.set_xlim(0, W); ax.set_ylim(H, 0); ax.axis("off")


def load(name):
    return Image.open(PARTS / name).convert("RGBA")


def put(img, x, y, scale_h):
    h = scale_h; w = img.width * scale_h / img.height
    ax.imshow(np.asarray(img), extent=(x, x + w, y + h, y), zorder=2, interpolation="lanczos")
    return w, h


class Face:
    """Face-on part image with a model (mm) to canvas mapping."""

    def __init__(self, key, x, y, s):
        m = META[key]
        self.m, self.x, self.y, self.s = m, x, y, s
        self.w = (m["xmax"] - m["xmin"]) * s
        self.h = (m["ymax"] - m["ymin"]) * s
        ax.imshow(np.asarray(load(m["file"])), extent=(x, x + self.w, y + self.h, y), zorder=2, interpolation="lanczos")

    def pt(self, X, Y):
        m = self.m
        px = self.x + ((X - m["xmin"]) if m["side"] == "front" else (m["xmax"] - X)) * self.s
        py = self.y + (m["ymax"] - Y) * self.s
        return (px, py)


def wire(pts, color, lw=6, z=5):
    pts = np.array(pts, dtype=float)
    ax.plot(pts[:, 0], pts[:, 1], color=COL[color], lw=lw, solid_capstyle="round", solid_joinstyle="round", zorder=z)
    ax.plot(*pts[0], "o", color=COL[color], ms=lw * 0.9, zorder=z + 1)
    ax.plot(*pts[-1], "o", color=COL[color], ms=lw * 0.9, zorder=z + 1)


def label(x, y, text, size=15, color="#222", ha="center", va="center", weight="normal", z=8, rot=0, box=False):
    kw = dict(bbox=dict(fc="white", ec="none", alpha=0.9, pad=1.5)) if box else {}
    ax.text(x, y, text, fontsize=size, color=color, ha=ha, va=va, weight=weight, zorder=z, rotation=rot, **kw)


NET = dict(GND=("black", "GND"), V3V3=("red", "3V3"), V5=("orange", "5V"))


def flag(x, y, net, dy=-40):
    """Power-net symbol on a vertical stub: ground bars for GND, a tag for 3V3 / 5V."""
    c, text = NET[net]
    ex, ey = x, y + dy
    ax.plot([x, ex], [y, ey], color=COL[c], lw=4, zorder=6)
    sgn = -1 if dy < 0 else 1
    if net == "GND":
        for i, wdt in enumerate((30, 20, 10)):
            ax.plot([ex - wdt / 2, ex + wdt / 2], [ey + sgn * i * 7] * 2, color=COL[c], lw=3.5, zorder=6)
    else:
        label(ex, ey + sgn * 18, text, size=13, color=COL[c], weight="bold")
    ax.plot(x, y, "o", color=COL[c], ms=7, zorder=7)


# ================================================================ parts
dk = Face("devkit", 1380, 440, 9.6)
cam = Face("cam", 520, 800, 9.4)
mic = Face("mic", 1900, 200, 14.0)
drv = Face("driver", 1250, 1380, 14.5)
chg = Face("charger", 470, 1380, 11.5)
lip = Face("lipo", 120, 1300, 8.4)

# display: real product photo, upright, header along the top edge
disp = load("display_photo_crop.png")
DSC = 0.40
DX0, DY0 = 440, 250
dw, dh = put(disp, DX0, DY0, disp.height * DSC)


def disp_pin(i):  # 0..7 = GND VCC SCL SDA RST DC CS BL, measured on the product photo
    return (DX0 + (174 + 62.28 * i) * DSC, DY0 + 34 * DSC)


def icon(name, x, y, h):
    im = load(name)
    w, hh = put(im, x, y, h)
    return x, y, w, hh


label(W / 2, 46, "AccessiSound v2 wiring", size=34, weight="bold")

# ================================================================ DevKit
label(dk.x + dk.w / 2, dk.y - 36, "ESP32-S3-DevKitC-1", size=21, weight="bold")
J1 = ['3V3', '3V3', 'RST', 'IO4', 'IO5', 'IO6', 'IO7', 'IO15', 'IO16', 'IO17', 'IO18', 'IO8', 'IO3', 'IO46', 'IO9', 'IO10', 'IO11', 'IO12', 'IO13', 'IO14', '5V', 'GND']
J3 = ['GND', 'IO43', 'IO44', 'IO1', 'IO2', 'IO42', 'IO41', 'IO40', 'IO39', 'IO38', 'IO37', 'IO36', 'IO35', 'IO0', 'IO45', 'IO48', 'IO47', 'IO21', 'IO20', 'IO19', 'GND', 'GND']


def dkp(name, nth=0):
    hits = [(X, 58.84 - 2.54 * k) for hdr, X in ((J1, -4.43), (J3, 18.43)) for k, l in enumerate(hdr) if l == name]
    return dk.pt(*hits[nth])


used = {"IO12", "IO13", "IO14", "IO15", "IO16", "IO17", "IO18", "IO8", "IO10", "IO11", "IO38", "IO39",
        "IO2", "IO42", "IO41", "IO0", "3V3", "5V", "GND"}
for hdr, X, side in ((J1, -4.43, -1), (J3, 18.43, 1)):
    for k, l in enumerate(hdr):
        px, py = dk.pt(X, 58.84 - 2.54 * k)
        ax.plot(px, py, "o", color="#d8b23a", ms=4.2, zorder=4)
        if l in used:
            label(px + side * 44, py, l, size=11.5, weight="bold", ha="center", z=6)
# DevKit GND / 3V3 pins get symbols too
flag(*dkp("3V3", 0), "V3V3", dy=0) if False else None

# ================================================================ display (signals)
label(DX0 + dw / 2, DY0 + dh + 30, "1.54 in ST7789 display, 240 x 240, SPI", size=18, weight="bold")
sig = [(2, "IO12", "yellow", 95, 1270), (3, "IO13", "green", 118, 1250), (4, "IO16", "white", 141, 1230),
       (5, "IO15", "purple", 164, 1210), (6, "IO14", "blue", 187, 1190), (7, "IO17", "orange", 210, 1170)]
for i, pin, c, ly, lx in sig:
    p0 = disp_pin(i); p1 = dkp(pin)
    wire([p0, (p0[0], ly), (lx, ly), (lx, p1[1]), (p1[0] - 8, p1[1])], c)
flag(*disp_pin(0), "GND", dy=-52)
flag(*disp_pin(1), "V3V3", dy=-52)

# ================================================================ camera
label(cam.x + cam.w / 2, cam.y - 34, "ESP32-CAM (AI-Thinker)", size=18, weight="bold")
for i in range(8):
    for X in (-36.23, -11.77):
        px, py = cam.pt(X, 78.5 + 2.54 * i)
        ax.plot(px, py, "o", color="#d8b23a", ms=4, zorder=4)
p_u0r = cam.pt(-11.77, 78.5 + 5 * 2.54)
p_u0t = cam.pt(-11.77, 78.5 + 6 * 2.54)
label(p_u0r[0] - 52, p_u0r[1], "U0R", size=10.5, box=True)
label(p_u0t[0] - 52, p_u0t[1], "U0T", size=10.5, box=True)
t18, t8 = dkp("IO18"), dkp("IO8")
wire([p_u0r, (1060, p_u0r[1]), (1060, t18[1]), (t18[0] - 8, t18[1])], "cyan")
wire([p_u0t, (1085, p_u0t[1]), (1085, t8[1]), (t8[0] - 8, t8[1])], "brown")
c5 = cam.pt(-36.23, 78.5); cg = cam.pt(-36.23, 78.5 + 2.54)
flag(c5[0], c5[1], "V5", dy=46)
flag(cg[0] + 22, cg[1], "GND", dy=46)
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

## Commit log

2026-09-16 Remove em dashes and simplify wording
    Replace all em dash (—) characters with plain punctuation across
    comments, docstrings, and README prose, and lightly simplify a few
    run-on sentences for readability. No code logic, build config values,
    or dependency version pins were changed.
    [main.cpp]
2026-09-16 Rewrite README plainly, fix real bugs, add hardware-free demo
    README: fix the broken clone URL (was a YOUR_USERNAME placeholder), drop
    the badges/shields and ASCII-art diagrams for a plain instructional style,
    replace the wiring diagram with a straight GPIO-to-pin list that also
    covers the two status LEDs and their resistors (missing from the old parts
    list even though the firmware drives them), and drop dead links to
    docs/wiring_diagram.png and docs/ultimate-version.md that don't exist in
    this repo. Also states plainly that no physical hardware has been built or
    photographed yet, so the wiring is a build plan, not a demonstrated result.
    Real bugs found and fixed while actually running the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
    [main.cpp]
